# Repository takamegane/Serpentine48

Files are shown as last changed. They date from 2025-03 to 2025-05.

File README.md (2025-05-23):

# Serpentine48
 
## 必要なパーツ
* RP2040 zero x2  
* 1N4148W SMDダイオード x48  
* TRRS ジャック x2
* kailh スイッチソケット(MX用) x42-48
* kailh スイッチソケット(choc用) x42-48
* cherry MX互換キースイッチor choc互換スイッチ x42-48  
* EC12互換ロータリーエンコーダ x0-6    
* キーキャップ   
* USB Type-cケーブル x1  
* 丸スペーサー M2x7mm x10
* 丸スペーサー M2X8mm以上 x6
* ネジ M2x4mm x32

## はんだ付けについて
一般的な自作キーボードと作業は同じです。ダイオードの向きには注意してください。  
RP2040 zeroはコンスルーもしくはピンヘッダでの取り付けとなります。向きに注意してください。
ブートスイッチ等が上にくる形ではんだ付けをしてください。

## ファームウェアについて
vialでキーマップを変更できます。基本的なファームとなっているため、好みに合わせてキーマップを作成しなおしてください。

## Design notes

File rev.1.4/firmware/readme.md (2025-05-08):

# serpentine48

serpentine48

*A short description of the keyboard/project*

* Keyboard Maintainer: [taka](https://github.com/taka)
* Hardware Supported: *The PCBs, controllers supported*
* Hardware Availability: *Links to where you can find this hardware*

Make example for this keyboard (after setting up your build environment):

    make serpentine48:default

Flashing example for this keyboard:

    make serpentine48:default:flash

See the [build environment setup](https://docs.qmk.fm/#/getting_started_build_tools) and the [make instructions](https://docs.qmk.fm/#/getting_started_make_guide) for more information. Brand new to QMK? Start with our [Complete Newbs Guide](https://docs.qmk.fm/#/newbs).

## Bootloader

Enter the bootloader in 3 ways:

* **Bootmagic reset**: Hold down the key at (0,0) in the matrix (usually the top left key or Escape) and plug in the keyboard
* **Physical reset button**: Briefly press the button on the back of the PCB - some may have pads you must short instead
* **Keycode in layout**: Press the key mapped to `QK_BOOT` if it is available

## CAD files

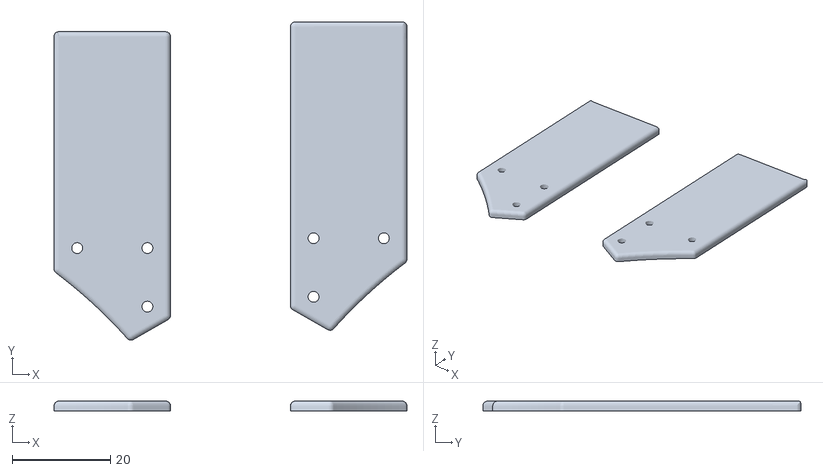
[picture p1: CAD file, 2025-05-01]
rev.1.4/case data/cover_plate.stl
71.8 x 64.7 x 2.00

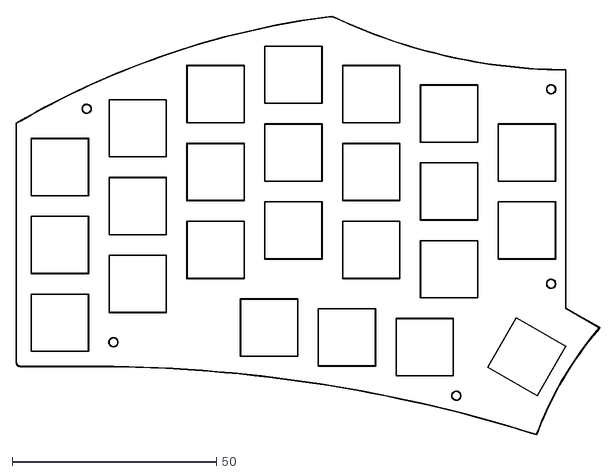
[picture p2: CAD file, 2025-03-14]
rev.1.4/plate data/Serpentine48_plate.dxf
143.0 x 102.5

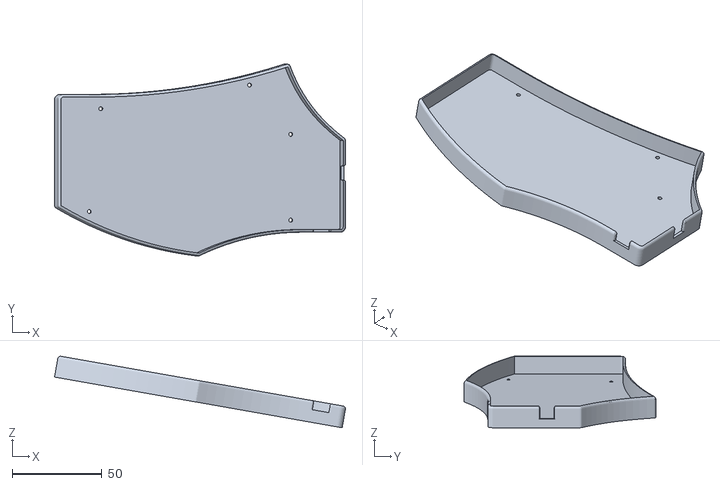
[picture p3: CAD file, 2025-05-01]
rev.1.4/case data/case_right.stl
161.7 x 106.5 x 39.8

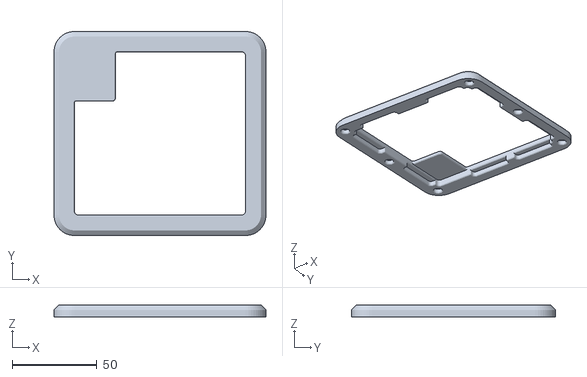
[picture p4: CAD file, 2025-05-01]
rev.1.4/case data/case_top.stl
125.0 x 120.2 x 7.35

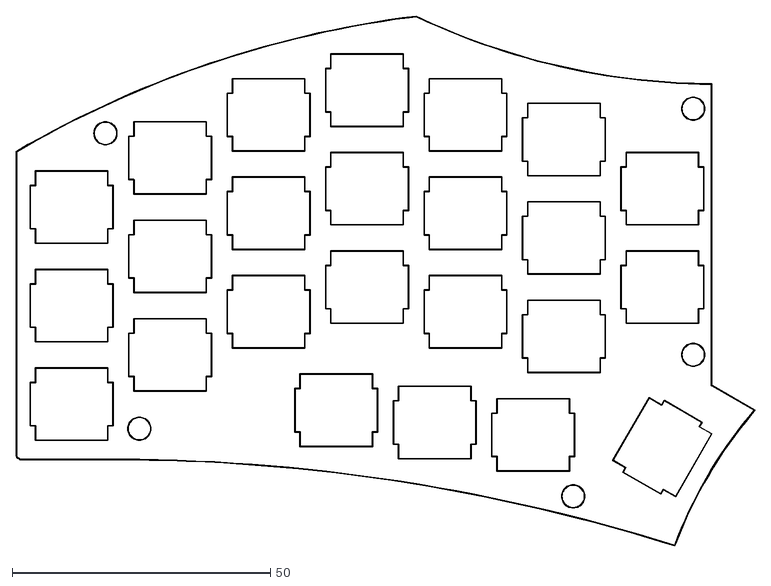
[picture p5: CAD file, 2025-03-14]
rev.1.4/plate data/Serpentine48_plate_middle.dxf
143.0 x 102.5

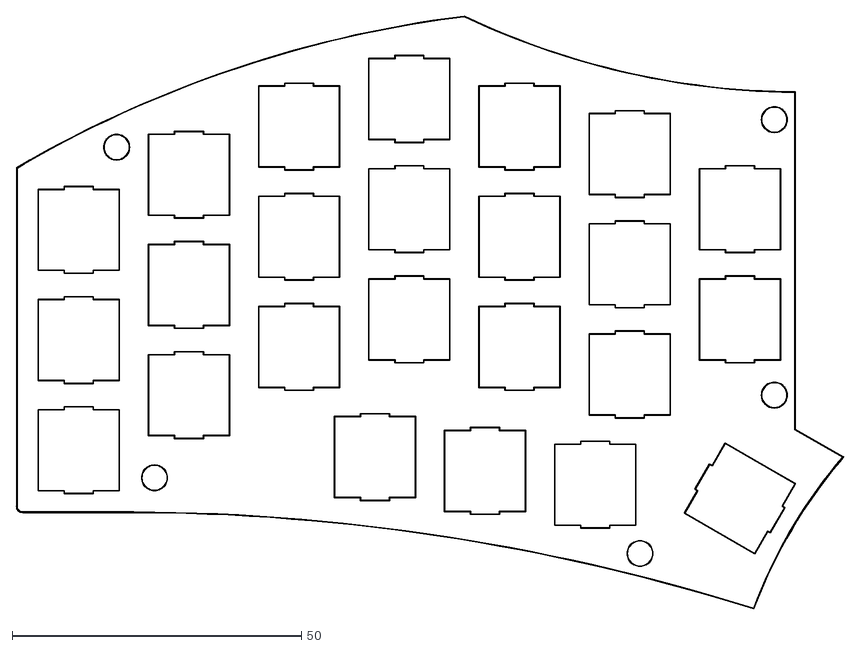
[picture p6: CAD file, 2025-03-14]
rev.1.4/plate data/Serpentine48_plate_middle_MX-Edge_Cuts.dxf
143.0 x 102.5

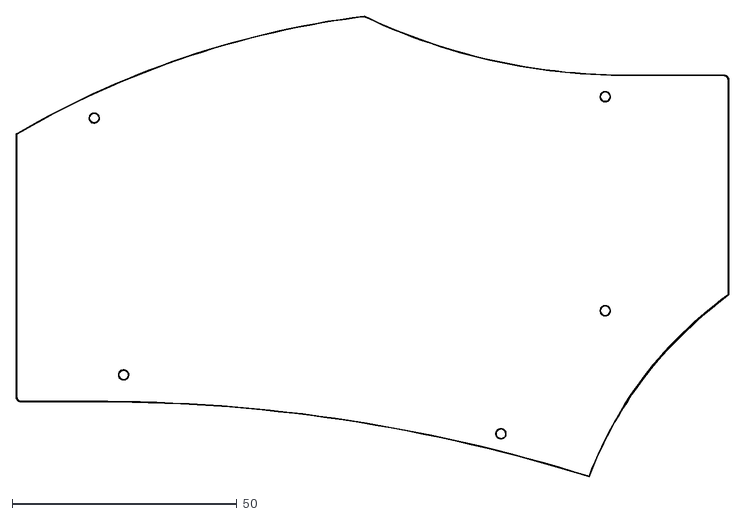
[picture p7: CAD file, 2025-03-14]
rev.1.4/plate data/Serpentine48_bottom.dxf
158.5 x 102.5

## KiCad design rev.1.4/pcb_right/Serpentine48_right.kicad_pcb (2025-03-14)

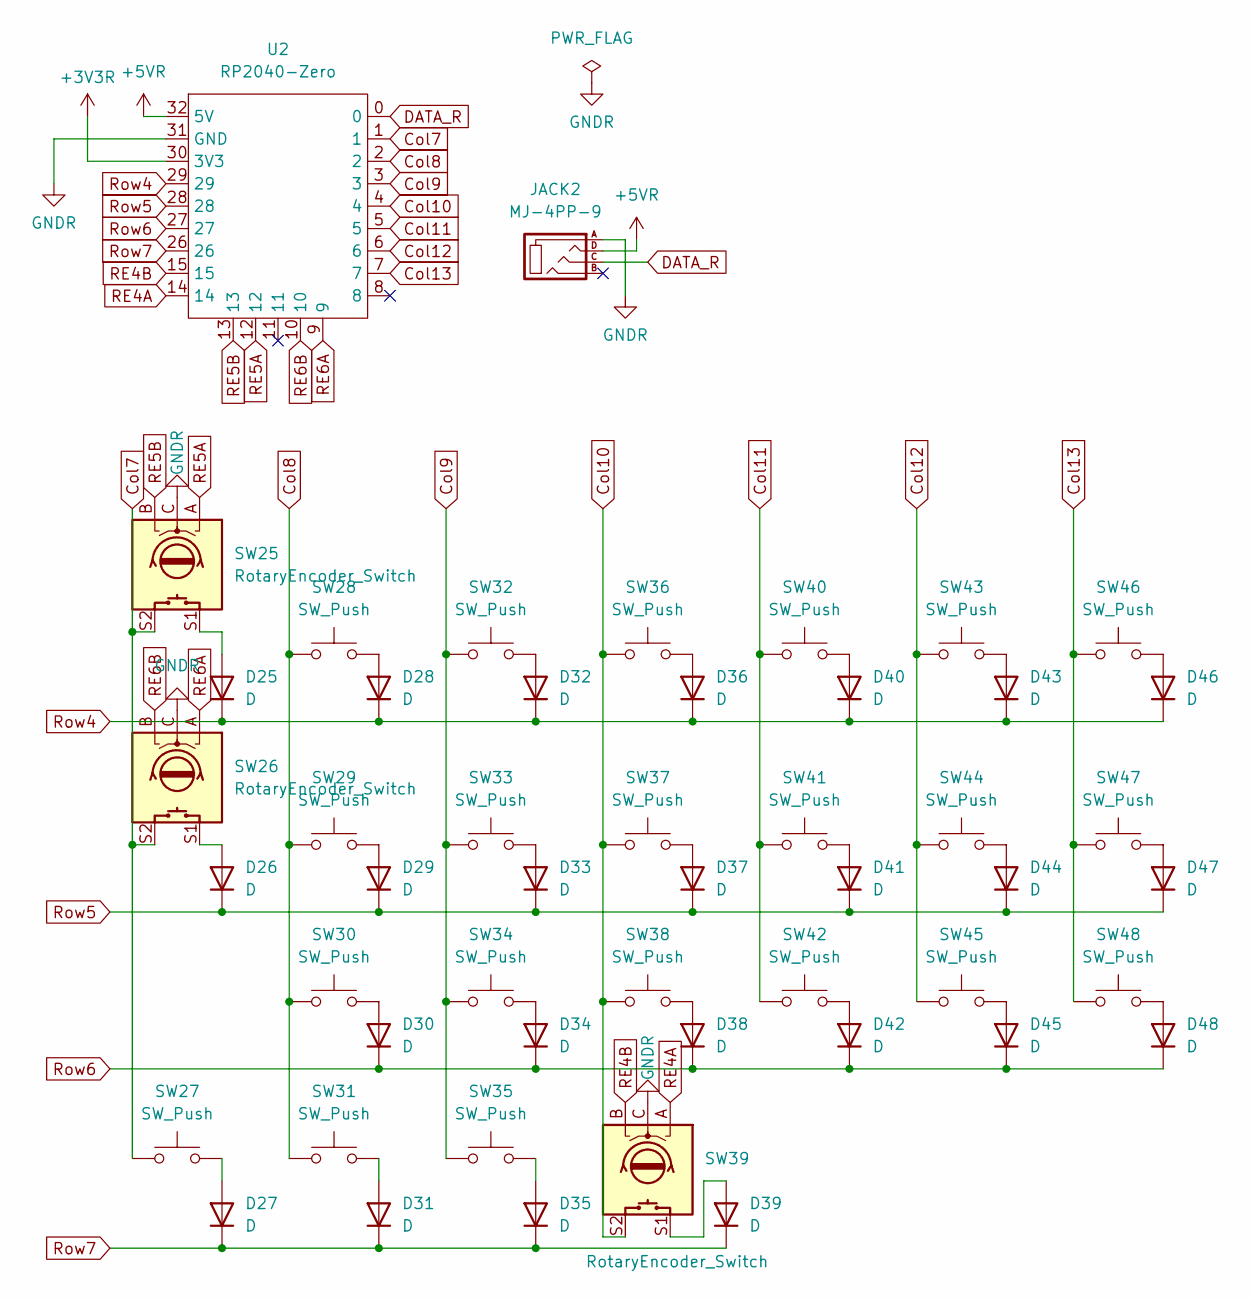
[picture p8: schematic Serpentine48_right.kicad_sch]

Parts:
D25, D26, D27, D28, D29, D30, D31, D32, D33, D34, D35, D36, D37, D38, D39, D40, D41, D42, D43, D44, D45, D46, D47, D48: D; Diode_SMD
JACK2: MJ-4PP-9; TRRS_MJ-4PP-9_1
SW25, SW26, SW39: RotaryEncoder_Switch; Kailh FullPOM MX_Hotswap_RE
SW27, SW28, SW29, SW30, SW31, SW32, SW33, SW34, SW35, SW36, SW37, SW38, SW40, SW41, SW42, SW43, SW44, SW45, SW46, SW47, SW48: SW_Push; Kailh FullPOM MX_Hotswap
U2: RP2040-Zero; RP2040 Zero

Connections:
+3V3R: U2.30 (3V3)
+5VR: JACK2.D, U2.32 (5V)
Col7: SW25.S2, SW26.S2, SW27.1, U2.1
Col8: SW28.1, SW29.1, SW30.1, SW31.1, U2.2
Col9: SW32.1, SW33.1, SW34.1, SW35.1, U2.3
Col10: SW36.1, SW37.1, SW38.1, SW39.S2, U2.4
Col11: SW40.1, SW41.1, SW42.1, U2.5
Col12: SW43.1, SW44.1, SW45.1, U2.6
Col13: SW46.1, SW47.1, SW48.1, U2.7
DATA_R: JACK2.C, U2.0
GNDR: JACK2.A, SW25.C, SW26.C, SW39.C, U2.31 (GND)
unnamed: D25.2 (A), SW25.S1
unnamed: D26.2 (A), SW26.S1
unnamed: D27.2 (A), SW27.2
unnamed: D28.2 (A), SW28.2
unnamed: D29.2 (A), SW29.2
unnamed: D30.2 (A), SW30.2
unnamed: D31.2 (A), SW31.2
unnamed: D32.2 (A), SW32.2
unnamed: D33.2 (A), SW33.2
unnamed: D34.2 (A), SW34.2
unnamed: D35.2 (A), SW35.2
unnamed: D36.2 (A), SW36.2
unnamed: D37.2 (A), SW37.2
unnamed: D38.2 (A), SW38.2
unnamed: D39.2 (A), SW39.S1
unnamed: D40.2 (A), SW40.2
unnamed: D41.2 (A), SW41.2
unnamed: D42.2 (A), SW42.2
unnamed: D43.2 (A), SW43.2
unnamed: D44.2 (A), SW44.2
unnamed: D45.2 (A), SW45.2
unnamed: D46.2 (A), SW46.2
unnamed: D47.2 (A), SW47.2
unnamed: D48.2 (A), SW48.2
RE4A: SW39.A, U2.14
RE4B: SW39.B, U2.15
RE5A: SW25.A, U2.12
RE5B: SW25.B, U2.13
RE6A: SW26.A, U2.9
RE6B: SW26.B, U2.10
Row4: D25.1 (K), D28.1 (K), D32.1 (K), D36.1 (K), D40.1 (K), D43.1 (K), D46.1 (K), U2.29
Row5: D26.1 (K), D29.1 (K), D33.1 (K), D37.1 (K), D41.1 (K), D44.1 (K), D47.1 (K), U2.28
Row6: D30.1 (K), D34.1 (K), D38.1 (K), D42.1 (K), D45.1 (K), D48.1 (K), U2.27
Row7: D27.1 (K), D31.1 (K), D35.1 (K), D39.1 (K), U2.26

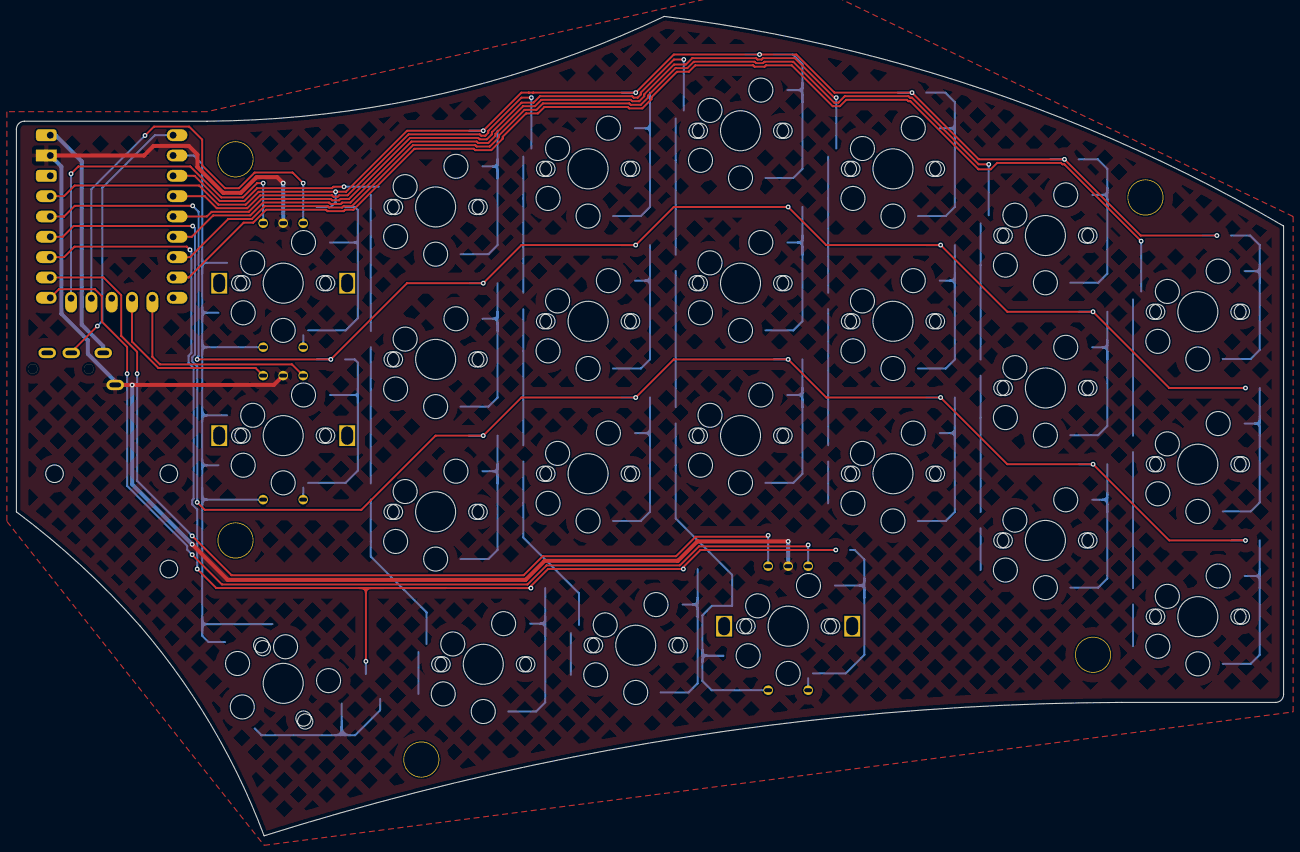
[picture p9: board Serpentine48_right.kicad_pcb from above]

Board: 2 copper layers, 158.4 x 102.4 mm, 58 parts (1 on the bottom side), 44 nets.

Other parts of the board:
Ref**: Val**; m2_Screw_Hole
Ref**#2, Ref**#5: Val**; m2_Screw_Hole
Ref**#3, Ref**#4, Ref**#6, Ref**#7, Ref**#8: Val**; m2_Spacer_Hole

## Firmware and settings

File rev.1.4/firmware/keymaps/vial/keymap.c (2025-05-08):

// Copyright 2023 QMK
// SPDX-License-Identifier: GPL-2.0-or-later

#include QMK_KEYBOARD_H

   const uint16_t PROGMEM keymaps[][MATRIX_ROWS][MATRIX_COLS] = {
	[0] = LAYOUT(
		KC_TAB,          KC_Q,           KC_W,         KC_E,          KC_R,          KC_T,          KC_HOME,       KC_MUTE, KC_Y,       KC_U,       KC_I,       KC_O,       KC_P,       KC_BSPC,
		RCTL_T(KC_CAPS), KC_A,           KC_S,         KC_D,          KC_F,          KC_G,          KC_END,        KC_ESC,  KC_H,       KC_J,       KC_K,       KC_L,       KC_SCLN,    KC_QUOT,
		KC_LSFT,         KC_Z,           KC_X,         KC_C,          KC_V,          KC_B,                                  KC_N,       KC_M,       KC_COMM,    KC_DOT,     KC_SLSH,    RSFT(KC_ENT),
		                                               KC_PSCR,       KC_LOPT,       MO(1),         KC_BSPC,       KC_SPC,  MO(2),      KC_RALT,    KC_PSCR
	),
	[1] = LAYOUT(
		KC_TAB,          LSFT(KC_1),     LSFT(KC_2),   LSFT(KC_3),    LSFT(KC_4),    LSFT(KC_5),    KC_TRNS,       KC_TRNS, LSFT(KC_6), LSFT(KC_7), LSFT(KC_8), LSFT(KC_9), LSFT(KC_0), KC_BSPC,
		KC_LCTL,         LCTL(KC_A),     LCTL(KC_S),   LCTL(KC_D),    LCTL(KC_F),    LCTL(KC_G),    KC_TRNS,       KC_TRNS, KC_LEFT,    KC_DOWN,    KC_UP,      KC_RGHT,    KC_NO,      KC_NO,
		KC_LSFT,         LCTL(KC_Z),     LCTL(KC_X),   LCTL(KC_C),    LCTL(KC_V),    LCTL(KC_B),                            KC_NO,      KC_NO,      KC_NO,      KC_NO,      KC_NO,      KC_NO,
		                                               KC_TRNS,       KC_TRNS,       KC_TRNS,       KC_TRNS,       KC_TRNS, MO(3),      KC_TRNS,    KC_TRNS
	),
	[2] = LAYOUT(
		KC_ESC,         KC_1,           KC_2,         KC_3,          KC_4,          KC_5,          KC_TRNS,       KC_TRNS, KC_6,       KC_7,       KC_8,       KC_9,       KC_0,       KC_DEL,
		KC_LCTL,         KC_MINS,        KC_EQL,       KC_LBRC,       KC_RBRC,       KC_BSLS,       KC_TRNS,       KC_TRNS, KC_F1,      KC_F2,      KC_F3,      KC_F4,      KC_F5,      KC_F6,
		KC_LSFT,         LSFT(KC_MINS),  LSFT(KC_EQL), LSFT(KC_LBRC), LSFT(KC_RBRC), LSFT(KC_BSLS),                         KC_F7,      KC_F8,      KC_F9,      KC_F10,     KC_F11,     KC_F12,
		                                               KC_TRNS,       KC_TRNS,       MO(3),         KC_TRNS,       KC_TRNS, KC_TRNS,    KC_TRNS,    KC_TRNS
	),
	[3] = LAYOUT(
		KC_NO,           KC_NO,          KC_NO,        KC_NO,         KC_NO,         KC_NO,         KC_TRNS,       KC_TRNS, KC_NO,      KC_NO,      KC_NO,      KC_NO,      KC_NO,      KC_NO,
		KC_NO,           KC_NO,          KC_NO,        KC_NO,         KC_NO,         KC_NO,         KC_TRNS,       KC_TRNS, KC_NO,      KC_NO,      KC_NO,      KC_NO,      KC_NO,      KC_NO,
		KC_NO,           KC_NO,          KC_NO,        KC_NO,         KC_NO,         KC_NO,                                 KC_NO,      KC_NO,      KC_NO,      KC_NO,      KC_NO,      KC_PSCR,
		                                               KC_TRNS,       KC_TRNS,       KC_TRNS,       KC_TRNS,       KC_TRNS, KC_TRNS,    KC_TRNS,    KC_TRNS
	)
};



const uint16_t PROGMEM encoder_map[][NUM_ENCODERS][NUM_DIRECTIONS] = {
    [0] = { ENCODER_CCW_CW(KC_WH_D, KC_WH_U),
            ENCODER_CCW_CW(KC_PGUP, KC_PGDN), 
            ENCODER_CCW_CW(KC_LEFT, KC_RIGHT), 
            ENCODER_CCW_CW(KC_UP, KC_DOWN), 
            ENCODER_CCW_CW(KC_VOLD, KC_VOLU),
            ENCODER_CCW_CW(KC_UP, KC_DOWN) 
          },
    [1] = { ENCODER_CCW_CW(KC_TRNS, KC_TRNS),
            ENCODER_CCW_CW(KC_TRNS, KC_TRNS), 
            ENCODER_CCW_CW(KC_TRNS, KC_TRNS), 
            ENCODER_CCW_CW(KC_TRNS, KC_TRNS), 
            ENCODER_CCW_CW(KC_TRNS, KC_TRNS),
            ENCODER_CCW_CW(KC_TRNS, KC_TRNS) 
          },
    [2] = { ENCODER_CCW_CW(KC_TRNS, KC_TRNS),
            ENCODER_CCW_CW(KC_TRNS, KC_TRNS), 
            ENCODER_CCW_CW(KC_TRNS, KC_TRNS), 
            ENCODER_CCW_CW(KC_TRNS, KC_TRNS), 
            ENCODER_CCW_CW(KC_TRNS, KC_TRNS),
            ENCODER_CCW_CW(KC_TRNS, KC_TRNS) 
          },
    [3] = { ENCODER_CCW_CW(KC_TRNS, KC_TRNS),
            ENCODER_CCW_CW(KC_TRNS, KC_TRNS), 
            ENCODER_CCW_CW(KC_TRNS, KC_TRNS), 
            ENCODER_CCW_CW(KC_TRNS, KC_TRNS), 
            ENCODER_CCW_CW(KC_TRNS, KC_TRNS),
            ENCODER_CCW_CW(KC_TRNS, KC_TRNS) 
          },
};
